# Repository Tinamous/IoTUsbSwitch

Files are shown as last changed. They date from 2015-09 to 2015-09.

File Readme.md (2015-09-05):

IoT USB Switch
--------------

USB Power switch. Control the power to a USB powered device (e.g. light) via an internet connected Particle Photon. 

Also measures current consumption as well as in and out voltages.

Rev1:
-----

Initial version. 3 boards build, appears to work!

Issues:
* PCB was a little too long and needed a small amount removed at the USB plug.
* With headers and a socket the Photon is very tall. It's mounted on the bottom of the board with USB plug and socket on the top which makes it a little odd.
* Photon in headers is about the same height as a Double USB socket, LM3526M-L is a dual output device so Rev2 probably worth making dual output as little extra expence.

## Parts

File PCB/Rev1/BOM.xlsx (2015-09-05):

Part | Value | Supplier | Supplier Code | Mfg Code | Note
IC3 | ACS712 |  |  |  | Current Monitor
IC2 | LM3526M-L |  |  |  | USB Switch
IC1 | Photon | Particle.io | Photon |  | With Headers
JP1 |  | Farnell | 1696546 | MC32605 | USB Plug - SMD
JP2 |  | Farnell | ? |  | USB Socket - Through Hole
C1 | 1nf-100nF |  |  |  | 805
C2 | 0.1uF |  |  |  | 805
C3 | Missing
C4 | 1uF
C5 | 1uF
R1 | 10k |  |  |  | 1206
R2 | 10k |  |  |  | 1206
R3 | 10k |  |  |  | 1206
R3 | 10k |  |  |  | 1206
R5 | 10k |  |  |  | 1206
R6 | Missing
R7 | 10k |  |  |  | 1206
S1 |  |  |  |  | Optional

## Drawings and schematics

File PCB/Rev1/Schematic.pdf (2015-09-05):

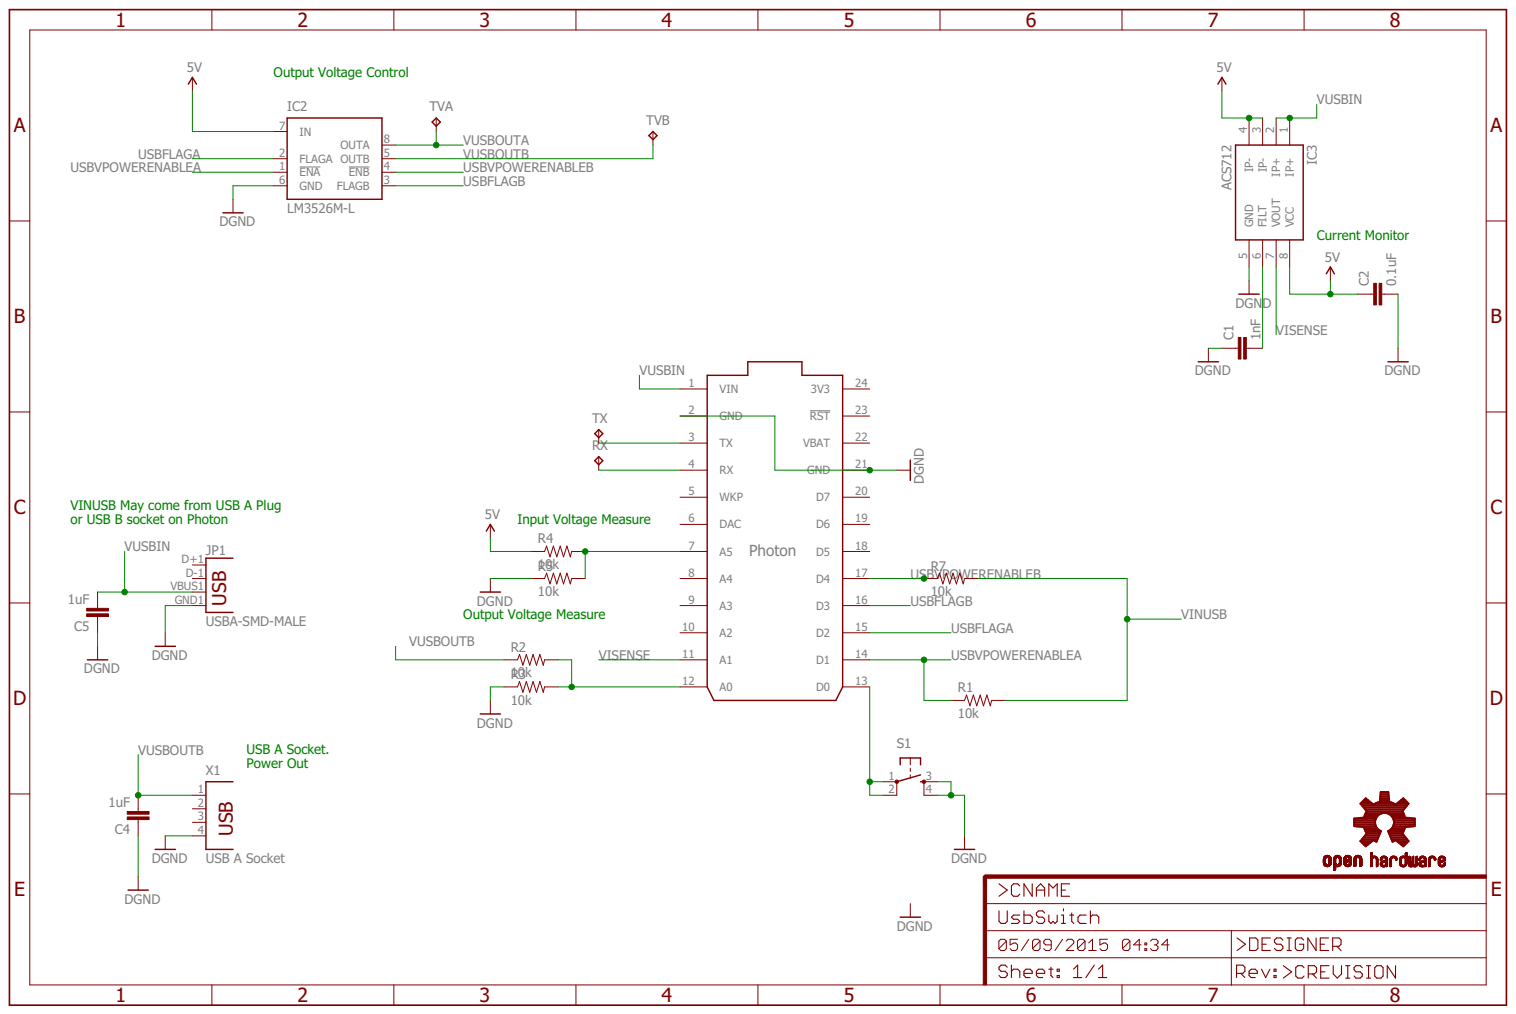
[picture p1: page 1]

VINUSB May come from USB A Plug
or USB B socket on Photon

USB A Socket. Power Out

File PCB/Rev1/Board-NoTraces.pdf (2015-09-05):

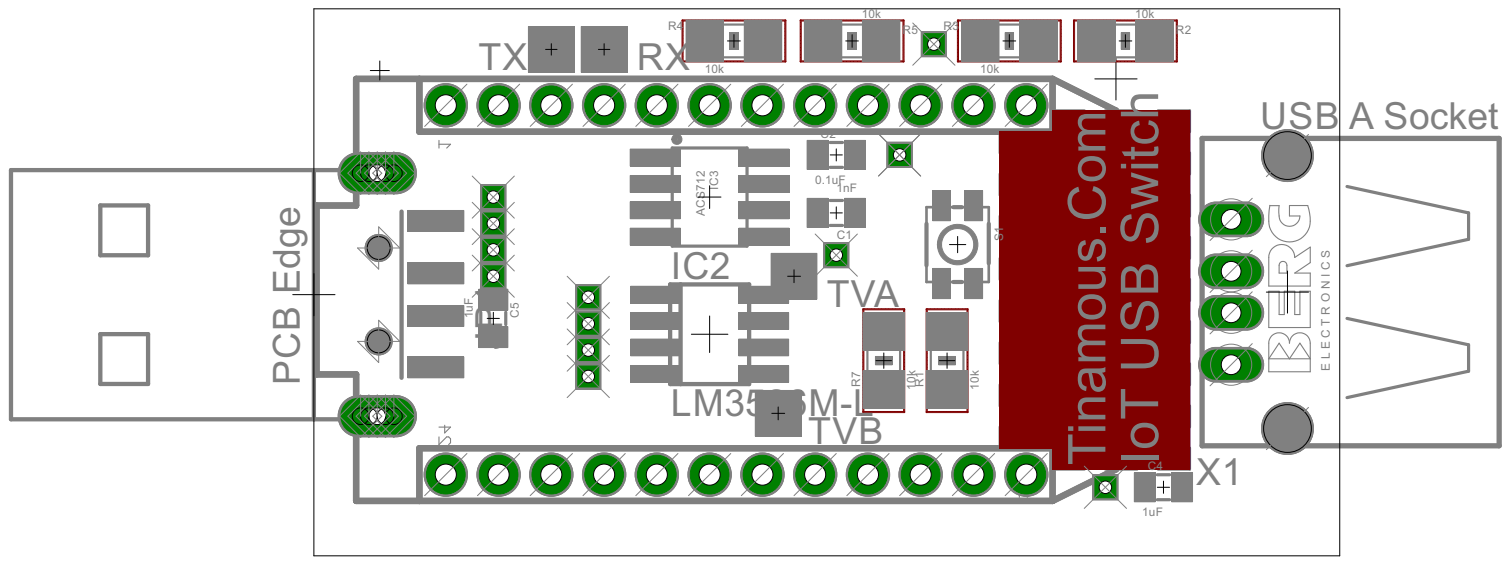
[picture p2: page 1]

PHOTON U$1 E L E C T R O N I C S PCB Edge Tinamous.Com IoT USB Switch JP1 X1 R4 R5 R3 R2 IC3 C1 C2 C4 C5 TX RX S1 R1 IC2 R7 TVA TVB USB A Socket 10k 10k 10k 10k ACS712 1nF 0.1uF 1uF 1uF TPTP20SQ TPTP20SQ 10k LM3526M-L 10k TPTP20SQ TPTP20SQ

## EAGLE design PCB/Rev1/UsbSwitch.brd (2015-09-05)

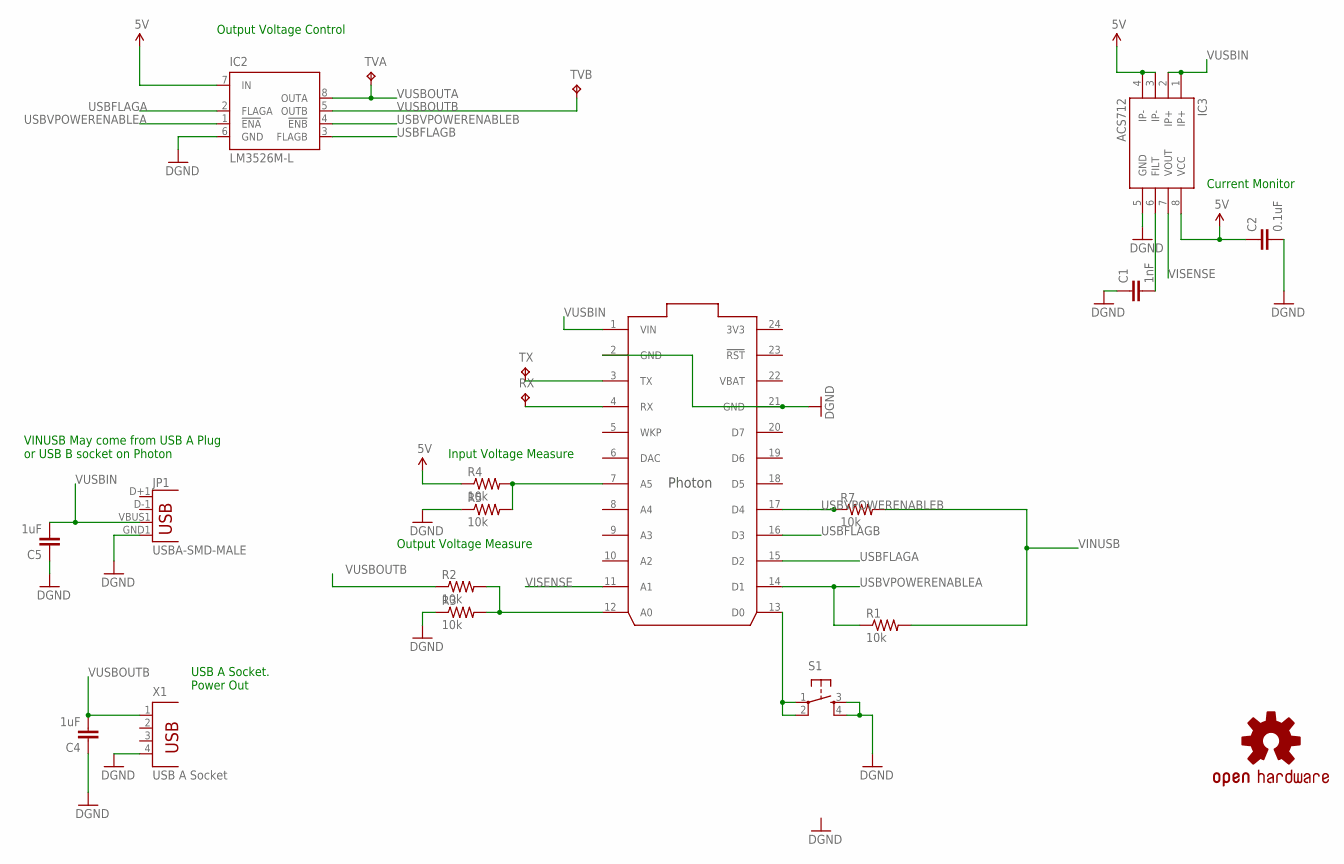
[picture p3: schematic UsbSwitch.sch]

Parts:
C1: 1nF; 0805
C2: 0.1uF; 0805
C4, C5: 1uF; 0805
IC1: PHOTON
IC2: LM3526M-L; SO08
IC3: ACS712; SO08
JP1: USBA-SMD-MALE; USB-A-SMT-MALE
LOGO1: OSHW-LOGOM-COPPER; OSHW-LOGO-M_COPPER
R1, R2, R3, R4, R5, R7: 10k; 1206
RX: TPTP20SQ; TP20SQ
S1: TAC_SWITCHSMD; TACTILE_SWITCH_SMD
TVA: TPTP20SQ; TP20SQ
TVB: TPTP20SQ; TP20SQ
TX: TPTP20SQ; TP20SQ
X1: USB A Socket; PN87520

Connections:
3V3: IC1.24 (3V3)
5V: C2.1, IC2.7 (IN), IC3.3 (IP-), IC3.4 (IP-), IC3.8 (VCC), R4.1
GND: C1.1, C2.2, C4.1, C5.1, IC1.2 (GND), IC1.21 (GND), IC2.6 (GND), IC3.5 (GND), JP1.GND1 (GND), R3.1, R5.1, S1.3, S1.4, X1.4
unnamed: IC1.13 (D0), S1.1, S1.2
unnamed: C1.2, IC3.6 (FILT)
unnamed: IC1.3 (TX), TX.TP
unnamed: IC1.4 (RX), RX.TP
unnamed: IC1.12 (A0), R2.2, R3.2
unnamed: IC1.7 (A5), R4.2, R5.2
USBFLAGA: IC1.15 (D2), IC2.2 (FLAGA)
USBFLAGB: IC1.16 (D3), IC2.3 (FLAGB)
USBVPOWERENABLEA: IC1.14 (D1), IC2.1 (!ENA), R1.1
USBVPOWERENABLEB: IC1.17 (D4), IC2.4 (!ENB), R7.1
VBAT: IC1.22 (VBAT)
VINUSB: R1.2, R7.2
VISENSE: IC1.11 (A1), IC3.7 (VOUT)
VUSBIN: C5.2, IC1.1 (VIN), IC3.1 (IP+), IC3.2 (IP+), JP1.VBUS1 (VBUS)
VUSBOUTA: IC2.8 (OUTA), TVA.TP
VUSBOUTB: C4.2, IC2.5 (OUTB), R2.1, TVB.TP, X1.1

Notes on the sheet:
VINUSB May come from USB A Plug or USB B socket on Photon
USB A Socket. Power Out
Output Voltage Measure
Input Voltage Measure
Output Voltage Control
Current Monitor

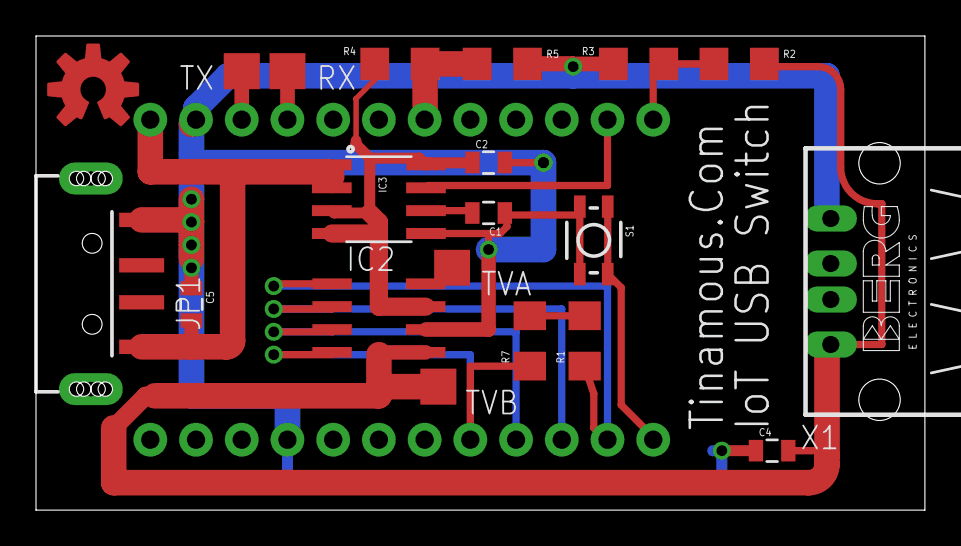
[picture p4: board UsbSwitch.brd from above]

Board: 2 copper layers, 49.4 x 26.3 mm, 21 parts (1 on the bottom side), 17 nets.

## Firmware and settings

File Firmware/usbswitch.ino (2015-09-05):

// **********************************************************************
// USB Switch
// **********************************************************************

// User switch S1
int switchPin = D0;  // Input
int usbEnableAPin = D1; // Output - Not used.
int usbFlagAPin = D2;  // Input - Not used.
int usbFlagBPin = D3;  // Input
int usbEnableBPin = D4; // Output

int VUsbOutPin = A0;
int ISensePin = A1;
int VUsbInPin = A5;
// Pin 3/4 Tx/Rx for serial avaiable as test points.


int vin = 0;
int vout = 0;
int current = 0;
int zeroCurrent = 0;
int state = 0;
int faultCode = 0;

int on(String command);
int off(String command);
int zero(String command);

void setup() {
    // Take control of the spark LED and make it dimmer as it's very
    // bright by default.
    RGB.control(true);
    RGB.brightness(10);
    RGB.color(0, 255, 0);
    
    pinMode(switchPin, INPUT);
    pinMode(usbFlagAPin, INPUT);
    pinMode(usbFlagBPin, INPUT);
    
    pinMode(usbEnableAPin, OUTPUT);
    pinMode(usbEnableBPin, OUTPUT);
    
    // LM3526M-L is active low, set HIGH to switch off.
    digitalWrite(usbEnableAPin, HIGH);
    digitalWrite(usbEnableBPin, HIGH);
    
    // Let the output settle and read the current level
    // with the output switched off. This is the baseline
    delay(1000);
    zeroCurrent = analogRead(ISensePin);
      
    Particle.variable("vin", &vin, INT);
    Particle.variable("vout", &vout, INT);
    Particle.variable("current", &current, INT);
    Particle.variable("zeroCurrent", &zeroCurrent, INT);
    Particle.variable("state", &state, INT);
    Particle.variable("faultCode", &faultCode, INT);

    // register the cloud function
    Particle.function("on", on);
    Particle.function("off", off);
    Particle.function("zero", zero);
    
    
    //delay(1000);
    Particle.publish("Status", "IoT Usb Switch Setup complete.");
    RGB.color(0, 0, 0);
}

void loop() {
    //setFan(4);
    //digitalWrite(ledSampling, HIGH);
    RGB.color(0, 0, 255);
    
    readLevels();
    
    // TODO: Read Current
    // Read VIn
    // Read VOut
    // Check error state of USB
    
    // Reset the fault code before measuring.
    faultCode = 0;

    // Small delay before re-reading to see if this helps resolve the errors.
    delay(1000);
    //readTemperature();
    
    RGB.color(0, 0, 0);

    // Do not use Sleep as it breaks Photon WiFi!
    // Can we put the Core into low power mode?
    // Photon:
    //System.sleep(2);
    // Core:
    // Spark.sleep(1);
    // Sleep for x seconds.
    delay(1000);
} 

int on(String command)
{
    Particle.publish("Status", "Switching on.");
    digitalWrite(usbEnableBPin, LOW);
    state = 1;
    readLevels();
    return 1;
}

// Particle Method
int off(String command)
{
    Particle.publish("Status", "Switching off.");
    digitalWrite(usbEnableBPin, HIGH);
    state = 0;
    readLevels();
    return 0;
}

// Particle Method
int zero(String command)
{
    int currentRead = analogRead(ISensePin);
    zeroCurrent = currentRead;
    Particle.publish("Status", "Zering current measurement at " + String(currentRead));
    return currentRead;
}

// Particle Method
int reset(String args) {
    // Photon only?
    Particle.publish("Status", "I'm going to reset in 2 seconds. Reason: " + args);
    delay(2000);
    System.reset();
    return 0;
}

void readLevels() {
    // read Voltage and current levels
    vout = analogRead(VUsbOutPin);
    vin = analogRead(VUsbInPin);
    
    // Sensor works + and - so zero current gives 5v/2 for zero current.
    // Current should only flow in one direction. Take the diff here and use that.
    int currentRead = analogRead(ISensePin);
    current = zeroCurrent - currentRead;
}

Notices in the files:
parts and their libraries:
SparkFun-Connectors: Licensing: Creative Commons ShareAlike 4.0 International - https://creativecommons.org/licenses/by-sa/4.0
